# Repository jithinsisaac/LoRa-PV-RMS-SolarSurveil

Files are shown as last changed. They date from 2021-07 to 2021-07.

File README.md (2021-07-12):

# LoRaWAN Enabled Remote Solar Photo Voltaic Energy Monitoring System  
## IEEE SIGHT & IEEE MTT-S funded project #19-SPC4-01  
## Project Duration: December 2019 to July 2021  

## Official Project Resources
- Website: [SolarSurveilDBIT.in](https://SolarSurveilDBIT.in)
- Analytical Web Device Management & Dashboard: Click [Sign Up / Login here](https://solarsurveildbit.in/index.html#services)
- Detailed Video: [@YouTube](https://youtu.be/FI_uH7AuqU8)  
- 3 minute video: [@YouTube](https://youtu.be/UwQO7I1e_y8)  

## Project Team Members:      
**Students & Faculty of Dept. of EXTC, Don Bosco Institute of Technology, Mumbai, India** [www.dbit.in](https://dbit.in)  

**Student Team Members**  
1. Shreyas Kulkarni
2. Keith Barnes
3. Shreyas Kulkarni
4. Aparna Kulkarni

**Faculty Team Members**
1. Dr. Ashwini Kotrashetti
2. Tayyabali Sayyad
3. Gejo George
4. Freda Carvalho
5. Jithin Saji Isaac (Project Guide)

## Project repository (PCB Design, Firmware Design & Web application code)

- All the source code required for PCB design, firmware development & web application development has been open sourced. Make maximum use of the same!

- All relevant information of the project can be obtained from the official website of the project at [SolarSurveilDBIT.in](https://SolarSurveilDBIT.in)  

- A seperate resources tab has been specially created on the website detailing each section of the project. Visit the [Solar Surveil Resources section](https://solarsurveildbit.in/resources.html)  

## Licenses

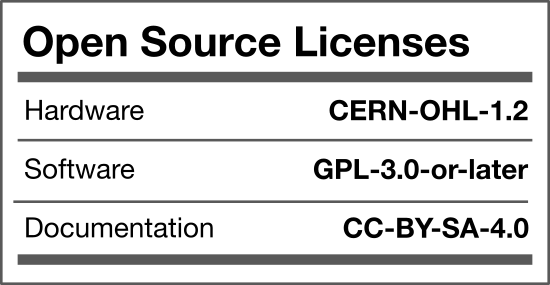
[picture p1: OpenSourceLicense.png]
License


- **Software/Firmware License:** GNU AGPL v3.0 license. See the LICENSE file for more information.   
- **PCB Design Hardware License:** CERN Open Hardware Licence v1.2. See the LICENSE_HARDWARE file for more information.  
- **Documentation License:** CC BY-SA 4.0    

## Credits

- [Solar Surveil Web application & Dashboard](https://github.com/sdk694/SolarSurveil) by  [Shreyas Kulkarni](https://twitter.com/sdk694)  
- [Microchip WLR089U0 based LoRaWAN energy monitoring end node PCB design & firmware](https://github.com/jithinsisaac/LoRa-PV-RMS-SolarSurveil/tree/main/PCB_WLR089U0_Board) by  [Keith Barnes](https://twitter.com/@sir_keith_)   
- [ESP32 ATM90E26 based Single Phase AC energy monitoring end node design & firmware](https://github.com/jithinsisaac/LoRa-PV-RMS-SolarSurveil/tree/main/PCB_ESP32_ATM90E26_Board) by [Adish Sthalekar](https://instagram.com/adish_sthalekar)     
- [Grafana, InfluxDB & NodeRED integrations](https://solarsurveildbit.in/blogak.html) by [Aparna Kulkarni](https://twitter.com/)  
- Project Ideation & Mentoring by [Dr. Ashwini Kotrashetti](http://ashwiniprofile-dbit.blogspot.com/)  
- Web application mentoring by [Tayyabali Sayyad](https://tayyabali.in/)  
- Project Guide, Embedded-IoT, [LoRaWAN](https://github.com/search?q=user%3Ajithinsisaac+lora) & PCB design expertise by [Jithin Saji Isaac](https://jithinsisaac.github.io/)   [@jithinisaac](https://twitter.com/jithinisaac)

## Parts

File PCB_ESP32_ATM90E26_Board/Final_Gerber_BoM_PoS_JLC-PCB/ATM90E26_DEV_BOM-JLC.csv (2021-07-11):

Comment | Designator | Footprint | LCSC
10uF | C1,C2 | Capacitor_SMD:C_1206_3216Metric_Pad1.42x1.75mm_HandSolder | C13585
27pF | C11,C12 | Capacitor_SMD:C_0805_2012Metric_Pad1.15x1.40mm_HandSolder | C8031
0.1uF | C13,C15,C16 | Capacitor_SMD:C_0805_2012Metric_Pad1.15x1.40mm_HandSolder | C49678
22uF | C4 | Capacitor_SMD:C_0805_2012Metric_Pad1.15x1.40mm_HandSolder | C45783
100nF | C3,C6 | Capacitor_SMD:C_0805_2012Metric_Pad1.15x1.40mm_HandSolder | C49678
10uF | C5,C7,C17 | Capacitor_SMD:C_0805_2012Metric_Pad1.15x1.40mm_HandSolder | C15850
330nF | C8,C18 | Capacitor_SMD:C_0805_2012Metric_Pad1.15x1.40mm_HandSolder | C1740
33nF | C9,C10 | Capacitor_SMD:C_0805_2012Metric_Pad1.15x1.40mm_HandSolder | C1739
LED'1206' | D2 | LED_SMD:LED_1206_3216Metric_Pad1.42x1.75mm_HandSolder | C84270
USB_B_Micro | J10 | JithinIsaac_Footprints:MicroUSB-LCSC-C21377-Sunrom-4358 | C21377
Conn_01x02_Male | J1,J2,J3,J4,J5,J6,J11,J12,J13,J14 | Connector_PinHeader_2.54mm:PinHeader_1x02_P2.54mm_Vertical | C124375
AudioJack4 | J7 | Connector_Audio:Jack_3.5mm_PJ320D_Horizontal | C95562
Barrel_Jack_Switch | J8 | new_Connector_BarrelJack:BarrelJack_CLIFF_FC681465S_SMT_Horizontal | C319134
Connector_Conn_01x06_Female | J9 | Connector_PinHeader_2.54mm:PinHeader_1x06_P2.54mm_Vertical | C190819
18 | R1 | Resistor_SMD:R_1206_3216Metric_Pad1.42x1.75mm_HandSolder | C247146
1.8K | R11,R12 | Resistor_SMD:R_0805_2012Metric_Pad1.15x1.40mm_HandSolder | C17398
12R | R13 | Resistor_SMD:R_1206_3216Metric_Pad1.42x1.75mm_HandSolder | C25352
100R | R14,R15 | Resistor_SMD:R_1206_3216Metric_Pad1.42x1.75mm_HandSolder | C17901
100K | R4,R16 | Resistor_SMD:R_1206_3216Metric_Pad1.42x1.75mm_HandSolder | C17900
1K | R9,R10,R17 | Resistor_SMD:R_1206_3216Metric_Pad1.42x1.75mm_HandSolder | C4410
470K | R2,R3,R6,R7 | Resistor_SMD:R_0805_2012Metric_Pad1.15x1.40mm_HandSolder | C17709
10K | R5,R8 | Resistor_SMD:R_0805_2012Metric_Pad1.15x1.40mm_HandSolder | C17414
JUMPER-PAD-3-NOFULL_BOX_SILK | SJ1,SJ2,SJ3 | Jumper:SolderJumper-3_P1.3mm_Open_RoundedPad1.0x1.5mm
GND | TP1 | TestPoint:TestPoint_Pad_D2.0mm
3.3V | TP2 | TestPoint:TestPoint_Pad_D2.0mm
ESP32-WROOM-32 | U1 | RF_Module:ESP32-WROOM-32 | C473012
ATM90E26-YU-B | U2 | atm_footprint:SSOP-28 | C145595
AMS1117-3.3 | U3 | Package_TO_SOT_SMD:SOT-223-3_TabPin2 | C6186
8.192 MHz | Y1 | Crystal:Crystal_SMD_HC49-SD_HandSoldering | C259042
SW_Push | sw1,sw2 | WLR089u0-DevBoard:Tactile Switch 3x4x2mm | C455280

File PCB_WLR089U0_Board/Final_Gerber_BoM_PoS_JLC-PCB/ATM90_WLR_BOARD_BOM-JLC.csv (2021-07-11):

Comment | Designator | Footprint | LCSC
Battery_Cell | BT1 | Connector_JST:JST_EH_B2B-EH-A_1x02_P2.50mm_Vertical | C265283
10uF | C1,C2 | Capacitor_SMD:C_0805_2012Metric_Pad1.15x1.40mm_HandSolder | C15850
4.7uF | C3,C4 | Capacitor_SMD:C_0805_2012Metric_Pad1.15x1.40mm_HandSolder | C1779
1uF | C5,C6 | Capacitor_SMD:C_0805_2012Metric_Pad1.15x1.40mm_HandSolder | C28323
100n | C7 | Capacitor_SMD:C_0805_2012Metric_Pad1.15x1.40mm_HandSolder | C49678
LED | D1 | LED_SMD:LED_0805_2012Metric_Pad1.15x1.40mm_HandSolder | C2296
DIODE_SCHOTTKY | D2,D5 | Diode_SMD:D_SOD-123 | C8598
Red | D3 | LED_SMD:LED_0805_2012Metric_Pad1.15x1.40mm_HandSolder | C2296
Green | D4 | LED_SMD:LED_0805_2012Metric_Pad1.15x1.40mm_HandSolder | C2296
WLR089U0-I_RM-SamacSys_Parts | IC1 | WLR089u0_Devboard:WLR089U0IRM | WLR089U0-I/RM
Barrel_Jack_Switch | J1 | Connector_BarrelJack:BarrelJack_CLIFF_FC681465S_SMT_Horizontal | C319134
Conn_ARM_JTAG_SWD_10 | J13 | Connector_PinHeader_1.27mm:PinHeader_2x05_P1.27mm_Vertical | C239059
AudioJack4 | J2 | Connector_Audio:Jack_3.5mm_PJ320D_Horizontal | C95562
SHUNT | J3 | TerminalBlock_Phoenix:TerminalBlock_Phoenix_MKDS-1,5-2-5.08_1x02_P5.08mm_Horizontal | C395868
Conn_01x02_Male | J4,J5,J7,J9,J10,J11,J12 | Connector_PinHeader_2.54mm:PinHeader_1x02_P2.54mm_Vertical | C124375
USB_B_Micro | J6 | JithinIsaac_Footprints:MicroUSB-LCSC-C21377-Sunrom-4358
Screw_Terminal_01x02 | J8 | TerminalBlock_Phoenix:TerminalBlock_Phoenix_MKDS-1,5-2-5.08_1x02_P5.08mm_Horizontal | C395868
SolderJumper_2_Open | JP1 | Jumper:SolderJumper-3_P1.3mm_Open_RoundedPad1.0x1.5mm
Q_PMOS_GSD | Q1 | Package_TO_SOT_SMD:SOT-23 | C10487
18 | R1 | Resistor_SMD:R_1206_3216Metric_Pad1.42x1.75mm_HandSolder | C247146
1k | R12,R13 | Resistor_SMD:R_0603_1608Metric_Pad1.05x0.95mm_HandSolder | C21190
100k | R11,R14 | Resistor_SMD:R_0603_1608Metric_Pad1.05x0.95mm_HandSolder | C25803
22k | R15 | Resistor_SMD:R_0603_1608Metric_Pad1.05x0.95mm_HandSolder | C31850
100K | R2 | Resistor_SMD:R_0603_1608Metric_Pad1.05x0.95mm_HandSolder | C25803
6.8K | R3 | Resistor_SMD:R_0603_1608Metric_Pad1.05x0.95mm_HandSolder | C23212
470K | R4,R5,R6,R7 | Resistor_SMD:R_0603_1608Metric_Pad1.05x0.95mm_HandSolder | C23178
470 | R8 | Resistor_SMD:R_0603_1608Metric_Pad1.05x0.95mm_HandSolder | C23179
10K | R9,R10 | Resistor_SMD:R_0603_1608Metric_Pad1.05x0.95mm_HandSolder | C25804
SW_Push | SW1 | WLR089u0_Devboard:Tactile Switch 3x4x2mm | C455280
TestPoint | TP1,TP2 | TestPoint:TestPoint_Pad_D2.0mm
MCP73831 | U1 | Package_TO_SOT_SMD:SOT-23-5_HandSoldering | C424093
MCP1700-3302E_SOT23 | U2 | Package_TO_SOT_SMD:SOT-23 | C39051
CH304E | U3 | Package_SO:MSOP-10_3x3mm_P0.5mm | C99652

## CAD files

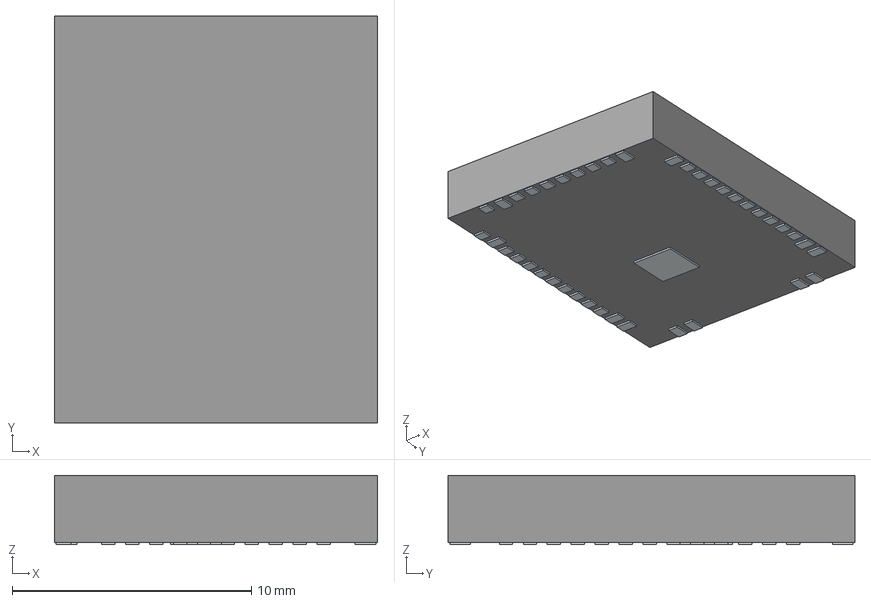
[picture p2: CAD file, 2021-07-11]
PCB_WLR089U0_Board/3DShapes/WLR089U0-I_RM.stp
13.5 x 17.0 x 2.90 mm
Pins

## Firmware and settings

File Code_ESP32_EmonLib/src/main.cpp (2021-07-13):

/* ESP32 MQTT with JSON
   Libraries used: Nick O'Leary PubSubClient@2.8 & ArduinoJson@6.17.3
   Author: Jithin Isaac  
   16 April 2021 */

#include <Arduino.h>
#include <Wifi.h>
#include <PubSubClient.h>
#include <ArduinoJson.h>
#include "EmonLib.h" // Include Emon Library 

#include <SPIFFS.h>
#include <WiFiSettings.h> //Using ESP-WiFiSettings by Juerd Waalboer

EnergyMonitor emon1;         // Create an instance
#define MEAS_METHOD_C0_CV1 0 //0 for current only, 1 for voltage-current

const char *brokerUser = "user_test";
const char *brokerPass = "extc@dbit";
const char *broker_url = "mqttbroker.dblabs.in";
const uint16_t broker_port = 1883;
const char *outTopic = "esp32/lora-pv-rms/tx";
const char *inTopic = "esp32/lora-pv-rms/rx";

WiFiClient espClient;
PubSubClient client(espClient);

void setupWifi()
{
  delay(100);
  Serial.print("\nConnecting to WiFi AP: ");
  //Serial.println(ssid);

  //WiFi.begin(ssid, pass);

  while (WiFi.status() != WL_CONNECTED)
  {
    delay(100);
    Serial.print("-");
  }

  Serial.print("\nConnected to WiFi AP: ");
  //Serial.println(ssid);
}

void reconnect()
{
  while (!client.connected())
  {
    Serial.print("\nConnecting to MQTT Broker @");
    Serial.println(broker_url);
    delay(100);
    Serial.print("-");
    if (client.connect("unique_client_name123", brokerUser, brokerPass))
    {
      Serial.print("\nConnected to MQTT Broker @");
      Serial.println(broker_url);
      client.subscribe(inTopic);
    }
    else
    {
      Serial.print("MQTT connection failed, rc=");
      Serial.print(client.state());
      Serial.println("\n Trying to reconnect in 5 seconds.");
      delay(5000);
    }
  }
  Serial.println();
}

void callback(char *topic, byte *payload, unsigned int length)
{
  Serial.print("Subscribing Payload: ");
  Serial.print(topic);
  Serial.print(": '");
  for (int i = 0; i < length; i++)
  {
    Serial.print((char)payload[i]);
  }
  Serial.println("'");
}

void setup()
{
  // put your setup code here, to run once:
  Serial.begin(115200);
  analogReadResolution(ADC_BITS); 
 
  //SPIFFS.format();
  SPIFFS.begin(true);  // Will format on the first run after failing to mount

  // Use stored credentials to connect to your WiFi access point.
  // If no credentials are stored or if the access point is out of reach,
  // an access point will be started with a captive portal to configure WiFi.
  // This is valid for a fresh firmware write on the esp32. 
  // Once wifi is set in this, then it just keeps reading from the eeprom
  // Doesnt ask for new password, even on fresh firmware rewrite. To enable that just do SPIFFS.format() before SPIFFS.begin(true); 
  WiFiSettings.connect();

  Serial.println("WiFi connected");

  //setupWifi(); //Normal WiFi.begin code, if not using WiFi Manager library

  client.setServer(broker_url, broker_port);
  client.setCallback(callback);

  if (!MEAS_METHOD_C0_CV1)
  {
    emon1.current(34, 70); // Current: input pin, calibration.  emon1.current(1, 111.1);
    Serial.println("Current only method, with apparent power.");
  }

  if (MEAS_METHOD_C0_CV1)
  {
    emon1.voltage(35, 234.26, 1.7); // Voltage: input pin, calibration, phase_shift
    emon1.current(34, 111.1);       // Current: input pin, calibration.
    Serial.println("Current & Voltage method, with real & apparent power.");
  }
}

int interval = 10000;
float realPower, apparentPower, powerFactor, supplyVoltage, Irms;
double energyWh = 0, energykWh = 0;
unsigned long previousTimeE = 0; //For Energy measurement
unsigned long previousTimeS = 0; //For data Sending interval

void loop()
{
  if (!client.connected())
  {
    reconnect();
  }
  client.loop();

  /* *********************** */
  /* Energy Payload generation */
  /* *********************** */

  //CURRENT ONLY METHOD WITH APPARENT POWER
  if (!MEAS_METHOD_C0_CV1)
  {
    Irms = emon1.calcIrms(1480); // Calculate Irms only
    apparentPower = Irms * 230.0;
    Serial.print("aP: ");
    Serial.print(apparentPower); // Apparent power
    Serial.print(" ");
    Serial.print("Irms: ");
    Serial.println(Irms); // Irms
  }

  //CURRENT & VOLTAGE METHOD WITH REAL & APPARENT POWER
  if (MEAS_METHOD_C0_CV1)
  {
    emon1.calcVI(20, 2000); // Calculate all. No.of half wavelengths (crossings), time-out
    emon1.serialprint();    // Print out all variables (realpower, apparent power, Vrms, Irms, power factor)

    realPower = emon1.realPower;         //extract Real Power into variable
    apparentPower = emon1.apparentPower; //extract Apparent Power into variable
    powerFactor = emon1.powerFactor;     //extract Power Factor into Variable
    supplyVoltage = emon1.Vrms;          //extract Vrms into Variable
    Irms = emon1.Irms;                   //extract Irms into Variable
  }

  unsigned long currentTimeE = millis();
  if (!MEAS_METHOD_C0_CV1)
    energyWh += (apparentPower * (unsigned long)(currentTimeE - previousTimeE)) / (3600 * 1000);
  if (MEAS_METHOD_C0_CV1)
    energyWh += (realPower * (unsigned long)(currentTimeE - previousTimeE)) / (3600 * 1000);

  energykWh = energyWh / 1000;
  previousTimeE = currentTimeE;

  /* *********************** */
  /* JSON Payload generation */
  /* *********************** */

  StaticJsonDocument<200> JSONbuffer;

  // Add values in the JSONbuffer document
  JSONbuffer["NodeID"] = "SS_AC_Node1";
  JSONbuffer["Voltage"] = supplyVoltage;
  JSONbuffer["Current"] = Irms;
  JSONbuffer["Apparent Power"] = apparentPower;
  JSONbuffer["Real Power"] = realPower;
  JSONbuffer["Power factor"] = powerFactor;
  if (!MEAS_METHOD_C0_CV1)
    JSONbuffer["Energy Wh"] = energyWh;
  if (MEAS_METHOD_C0_CV1)
    JSONbuffer["Energy Wh"] = energyWh;
  JSONbuffer["Energy kWh"] = energykWh;

  // Generate the minified Serialized JSON and send it to the Serial port for debugging
  Serial.println();
  //serializeJsonPretty(JSONbuffer, Serial);

  char jsonBufferMQTT[256]; //jsonBufferMQTT is the MQTT Payload
  serializeJson(JSONbuffer, jsonBufferMQTT);

  /* ********************** */
  /* JSON Tx via MQTT */
  /* ********************** */

  unsigned long currentTimeS = millis();
  if ((unsigned long)(currentTimeS - previousTimeS) > 5000)
  {
    Serial.print("Publishing JSON Message: ");
    Serial.println(jsonBufferMQTT); //Prints the JSON Payload that we are sending
    client.publish(outTopic, jsonBufferMQTT);
    previousTimeS = currentTimeS;
    //Serial.println(previousTimeS);
  }
}

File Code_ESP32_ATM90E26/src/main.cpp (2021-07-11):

/* 
Adapted from & Credits: https://github.com/whatnick/ATM90E26_Arduino
Status: Calibrating the ATM90E26 is a challenge. EmonLib is preferred.
Note: Whatnick has used ESP8266 for UART. Attempting to use ESP32. 
*/

#include <Arduino.h>
#include <energyic_UART.h>
#if !defined(ARDUINO_ARCH_SAMD) && !defined(ESP32)
#include <SoftwareSerial.h>
#else

#endif

#if defined(ESP8266)
//NOTE: Version 1.0 and 1.1 of featherwing use pins 14,12
//version 1.2 and above using pins 13,14
//SoftwareSerial ATMSerial(14, 12, false, 256); //RX, TX v1.0-1.1
//SoftwareSerial ATMSerial(13, 14, false, 256); //RX, TX v1.2+
SoftwareSerial ATMSerial(D4, D3, false, 256); //NodeMCU v1.0
#endif 

#ifdef __AVR_ATmega32U4__ //32u4 board
SoftwareSerial ATMSerial(11, 13); //RX, TX
#endif 

#if defined(ARDUINO_ARCH_SAMD)
#include "wiring_private.h" // pinPeripheral() function
//Feather M0 
#define PIN_SerialATM_RX       12ul
#define PIN_SerialATM_TX       11ul
#define PAD_SerialATM_RX       (SERCOM_RX_PAD_3)
#define PAD_SerialATM_TX       (UART_TX_PAD_0)

// Using SERCOM1 on M0 to communicate with ATM90E26
Uart ATMSerial(&sercom1, PIN_SerialATM_RX, PIN_SerialATM_TX, PAD_SerialATM_RX, PAD_SerialATM_TX);
#endif

#if defined(ESP32)
#define PIN_SerialATM_RX       16   //RX pin, USING UART2
#define PIN_SerialATM_TX       17   //TX pin, USING UART2
HardwareSerial ATMSerial(2);        //1 = just hardware serial number. ESP32 supports 3 hardware serials. UART 0 usually for flashing.
#endif

ATM90E26_UART eic(&ATMSerial);

void setup() {
  Serial.begin(115200);
  Serial.println("\nATM90E26 UART Test Started");
  
  #if defined(ARDUINO_ARCH_SAMD)
  pinPeripheral(PIN_SerialATM_RX, PIO_SERCOM);
  pinPeripheral(PIN_SerialATM_TX, PIO_SERCOM);
  #endif

  #if defined(ESP32)
  //Must begin ATMSerial before IC init supplying baud rate, serial config, and RX TX pins
  ATMSerial.begin(9600, SERIAL_8N1, PIN_SerialATM_RX, PIN_SerialATM_TX);
  #else
  //Must begin ATMSerial before IC init
  ATMSerial.begin(9600);
  #endif
  
  eic.InitEnergyIC();
  delay(1000);
}

void loop() {
  /*Repeatedly fetch some values from the ATM90E26 */
  Serial.print("Sys Status:");
  unsigned short s_status = eic.GetSysStatus();
  if(s_status == 0xFFFF)
  {
	#if defined(ESP8266)
    //Read failed reset ESP, this is heavy
    ESP.restart();
	#endif
  }
  Serial.println(eic.GetSysStatus(),HEX);
  delay(10);
  Serial.print("Meter Status:");
  Serial.println(eic.GetMeterStatus(),HEX);
  delay(10);
  Serial.print("Voltage:");
  #if defined(ESP32)
  //ESP32 or maybe another MCU support formatting float/double value
  Serial.printf("%.4f V\n", eic.GetLineVoltage());
  #else
  Serial.println(eic.GetLineVoltage());
  #endif
  delay(10);
  Serial.print("Current:");
  #if defined(ESP32)
  //ESP32 or maybe another MCU support formatting float/double value
  Serial.printf("%.4f A\n", eic.GetLineCurrent());
  #else
  Serial.println(eic.GetLineCurrent());
  #endif
  delay(10);
  Serial.print("Active power:");
  Serial.println(eic.GetActivePower());
  delay(10);
  Serial.print("p.f.:");
  Serial.println(eic.GetPowerFactor());
  delay(1000);
}

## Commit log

2021-07-11 Initial commit, merging different student repos
    [AC_RMS_ESP32_ATM90E26-2.sch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]
2021-07-13 Updated esp32-emonlib. Commit before trying WiFiManager library
2021-07-13 Added WiFiSettings/WiFiManager code. Now input ssid,pwd from external device. Saved in eeprom
